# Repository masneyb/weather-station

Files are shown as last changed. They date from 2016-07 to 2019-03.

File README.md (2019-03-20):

# Solar Powered Weather Station

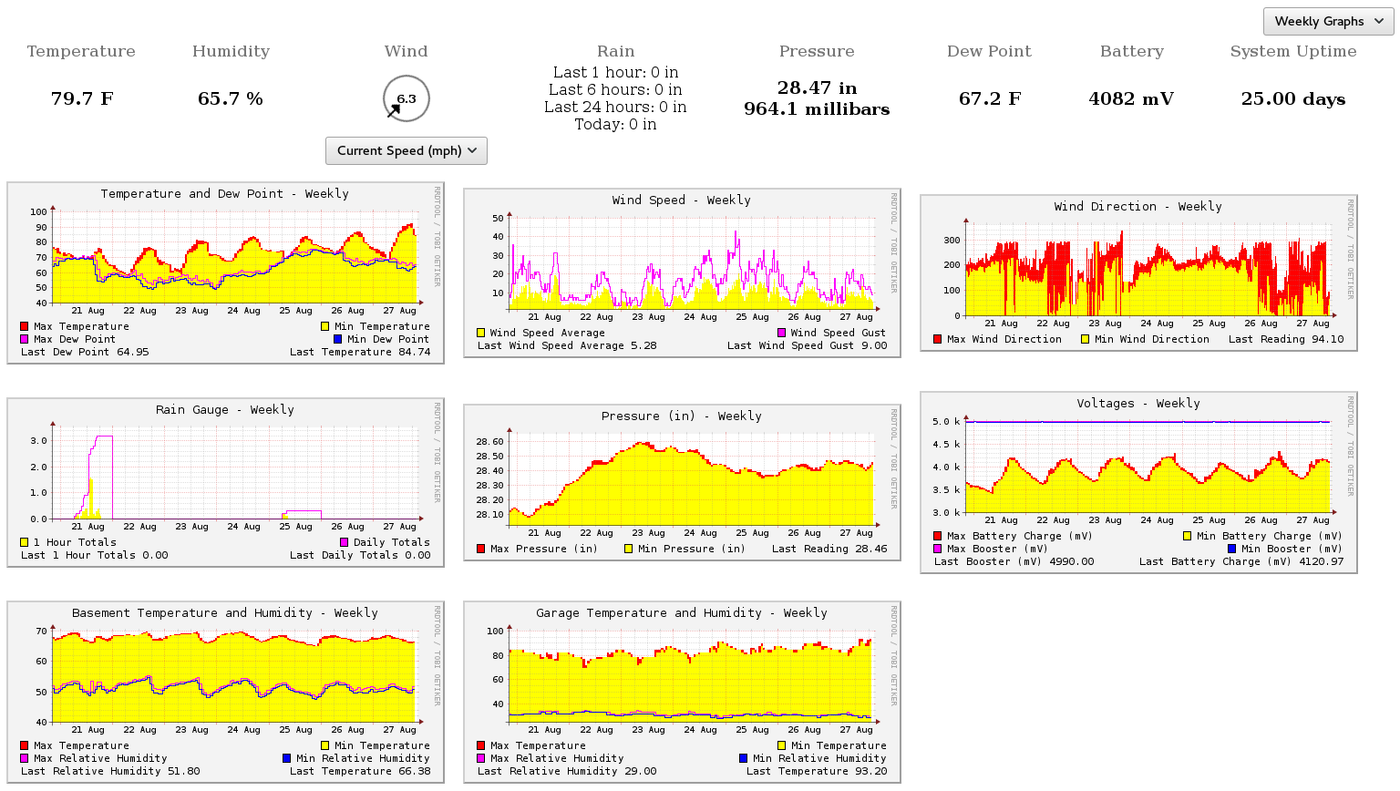
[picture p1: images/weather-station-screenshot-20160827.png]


## High level overview

- My [pi-yadl](pi-yadl) project is used to gather and graph the data from the following types
  of sensors:
  - [Argent Data Systems Weather Sensor Assembly](https://www.sparkfun.com/products/8942)
    contains a wind vane, anemometer, and rain gauge. The wind speed average and gusts
    over the last 2 minute, 10 minute and 60 minute periods are logged. The amount of
    rain over the last 1 hour, 6 hours, 24 hours, and since midnight are logged.
  - Supports various types of temperature and humidity sensors: DHT11, DHT22,
    DS18B20, TMP36 (analog).
  - Supports the BMP180 pressure, altitude and temperature sensor.
  - Battery charge level is read via an analog to digital converter (ADC).
- For the wind vane, wind speed and rain gauge, the pi-yadl program is ran
  as a daemon in the background so that it can continuously monitor the rain
  gauge and anemometer via interrupts. The values from these three sensors are
  written out to a RRD database and JSON file every 30 seconds. The wind speed
  values are updated internally every second so that it can obtain the correct
  wind gusts.
- The other sensors are polled every 5 minutes via a systemd timer and written
  to various RRD databases and JSON files.
- The RRD databases are used to show the historical readings and are
  recreated at the beginning of each hour.
- The web page uses Javascript and JQuery to download the various JSON files to
  provide a dashboard showing the current sensor readings. The web page checks
  for updated JSON files on the server every 10 seconds.
- The nginx webserver runs on the Pi and only needs to serve out static
  content. Everything runs on the Pi; no third-party services are required.
- Optional ability to publish the sensor readings to Weather Underground.
  You can
  [view my weather station on Weather Underground](https://www.wunderground.com/personal-weather-station/dashboard?ID=KWVMORGA45).

## Hardware Information

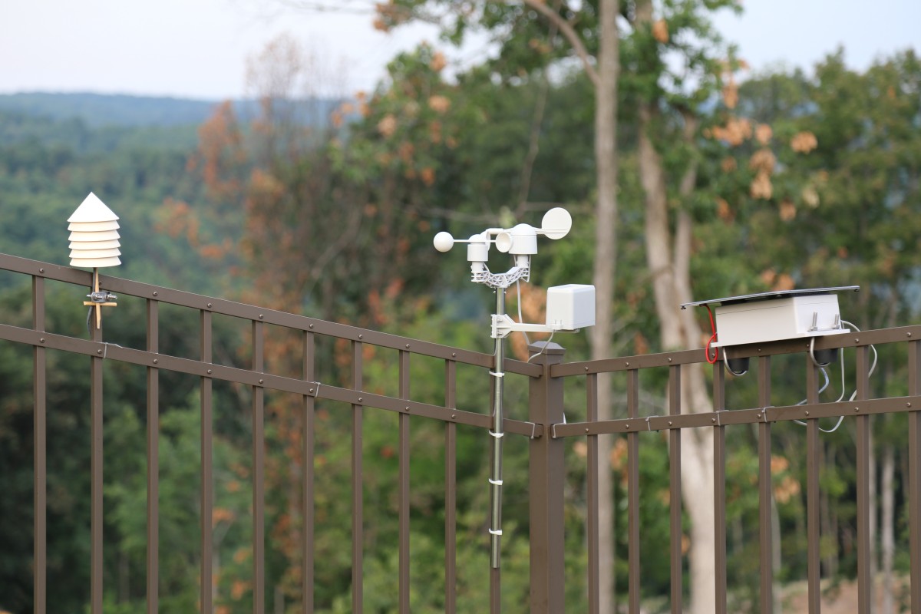
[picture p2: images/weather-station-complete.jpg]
Complete Setup


### Project Box

I used
[this project box on Amazon](https://www.amazon.com/uxcell%C2%AE-Waterproof-Connect-Junction-200x120x75mm/dp/B00O9YY1G2).
I was initially a little concerned about the quality of the seal on the box but
it has held up so after being outside continuously since June 2016.

All of the external sensors are terminated with a RJ45 connector to make it easy
to remove the project box without having to bring the entire weather station
inside. [RJ45 waterproof cable glands](https://www.adafruit.com/products/827)
are used on the project box to get the connections inside the box. The wire for
the solar panel enters the project box using a
[PG-9](https://www.adafruit.com/products/761) cable gland.

The box is mounted to the top of my fence using hose clamps with some rubber
stops that were purchased at a local hardware store.

### Solar and Power Setup

This weather station runs on a Raspberry Pi Zero running the latest Raspbian
Testing Lite. All of the hardware is powered by a
[6600mAH 3.7V lithium ion battery](https://www.adafruit.com/products/353)
that is [charged](https://www.adafruit.com/products/390) using a
[6V 9W solar panel](https://www.adafruit.com/products/2747). The 3.7V is
converted to 5V using a [PowerBoost 1000](https://www.adafruit.com/products/2465).
The solar panel is attached to the top of the project box using several large
pieces of Velcro. More information about the solar setup can be found on
[Adafruit's Website](https://learn.adafruit.com/usb-dc-and-solar-lipoly-charger/overview).
Be sure to connect the PowerBoost 1000 to the battery charge output pins; not to
the load terminal. This is because the solar panel can put out 6V however the
PowerBoost can only accept a maximum input voltage of 5.5V. See
[this post](https://forums.adafruit.com/viewtopic.php?f=19&t=59523) on the Adafruit
forums for more details. There should not be anything hooked up to the load
terminal on the charger. I fried a Pi Zero and a PowerBoost 1000 on a bright,
sunny afternoon with the PowerBoost hooked up to the load terminal.

To reduce the power usage of the Raspberry Pi, the LED and display on the Pi was
disabled. `powertop --auto-tune` was used to enable other power saving features.
See the files
[systemd/power-savings.service](systemd/power-savings.service) and
[bin/power-savings](bin/power-savings) for details. The power requirements
could be reduced even further by desoldering the various LEDs on the solar
charger and PowerBoost 1000.

I used a [USB Charger Doctor](https://www.adafruit.com/products/1852) to roughly
measure the power utilization of the entire weather station at 140 mAH with just
the wind / rain collector running in the background and 200 mAH when the main
collection processes runs every 5 minutes for just a few seconds. This is with a
USB WiFi dongle running the entire time. I would expect to get around 35 hours
of usage on a fully charged battery without any kind of backup from the solar
panel. See Power Disclaimer section below for more details.

The end of the solar panel is terminated with one of
[these waterproof cables](https://www.adafruit.com/products/744) to make it
easy to detach the solar panel from the box. This would also make it easy to
run an extension cord outside and plug the unit in to charge without removing
or disassembling the project box if there were several days in a row of very
cloudy weather.

I mounted this [waterproof on / off switch](https://www.adafruit.com/products/917)
on the project box. Two wires from the switch go to the run pins on the
PowerBoost 1000. I initially had it connected to the run pins on the Raspberry
Pi Zero but I ran into a situation where the weather station battery got very
low and I could not reset the Pi using the power button on the outside, even
after the battery was fully charged. Being able to completely power off the Pi
itself resolved that issue.

### Sensors

A [MCP3008 analog to digital converter](https://www.adafruit.com/products/856)
was soldered onto a [solderable breadboard](https://www.sparkfun.com/products/12070).
The ADC is used for the wind vane and obtaining the voltage levels from the
battery and PowerBoost 1000. This ADC communicates with the Raspberry Pi
using the SPI bus.

The wind vane supports reporting 16 different positions by using a series of
reed switches and different size resistors. The wind vane is connected to the
ADC and the voltage indicates the direction. For example, according to the 
[data sheet](http://www.sparkfun.com/datasheets/Sensors/Weather/Weather%20Sensor%20Assembly..pdf), 0 degrees (N)
is 3.84V; 45 degrees (NE) is 2.25V; and 90 degrees (E) is 0.45V. I had an issue
with getting accurate readings from the wind vane between 270 and 337.5 degrees
that was caused by having the reference ADC voltage in software set to 5V
instead of 5.1V when converting the value read from the ADC to millivolts.
Adding the argument `--adc_millivolts 5100` to the yadl binary fixed the issue.

The anemometer is hooked up to a GPIO pin on the Pi. According to the
[data sheet](http://www.sparkfun.com/datasheets/Sensors/Weather/Weather%20Sensor%20Assembly..pdf), one click
of the reed switch over a second corresponds to a wind speed of 1.492 mph
(2.4 km/h). A pull down resistor is used and the switch is debounced in
software. One complete revolution of the anemometer will cause the pin to go
high twice.

The rain gauge is very similar to the anemometer. Each click of the switch
over a second corresponds to 0.011 inches (0.2794 mm) of rain according to
the [data sheet](http://www.sparkfun.com/datasheets/Sensors/Weather/Weather%20Sensor%20Assembly..pdf).
This also uses a pull down resistor and the switch is debounced in
software.

The Stevenson screen (left side of the above picture) contains the temperature,
humidity and barometric pressure sensors. A 3D model of the screen was
downloaded from
[https://www.thingiverse.com/thing:158039](https://www.thingiverse.com/thing:158039),
3D printed using HIPS plastic and spray painted using flat white paint.

The temperature and humidity is obtained using a DHT22 sensor. The dew point is
calculated using the
[August-Roche-Magnus approximation](http://andrew.rsmas.miami.edu/bmcnoldy/Humidity.html).
The DHT sensor communicates with the Pi over one of the GPIO pins.

A BMP180 sensor is used to obtain the barometric pressure and communicates with
the Pi over the i2c bus. The BMP180 driver came from
[this project](https://github.com/lexruee/bmp180).

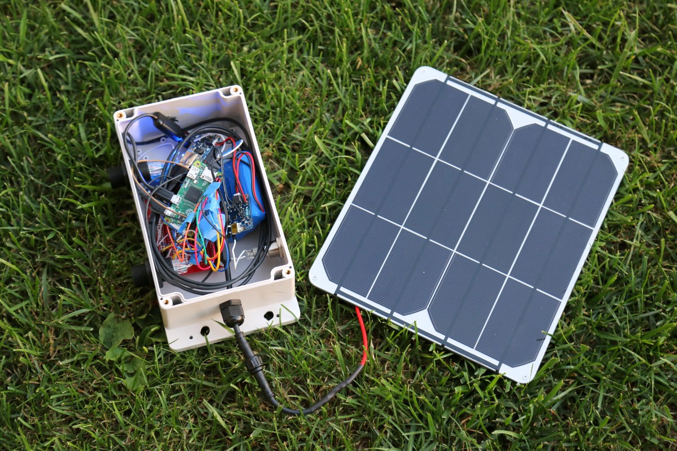
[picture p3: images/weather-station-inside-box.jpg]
Inside


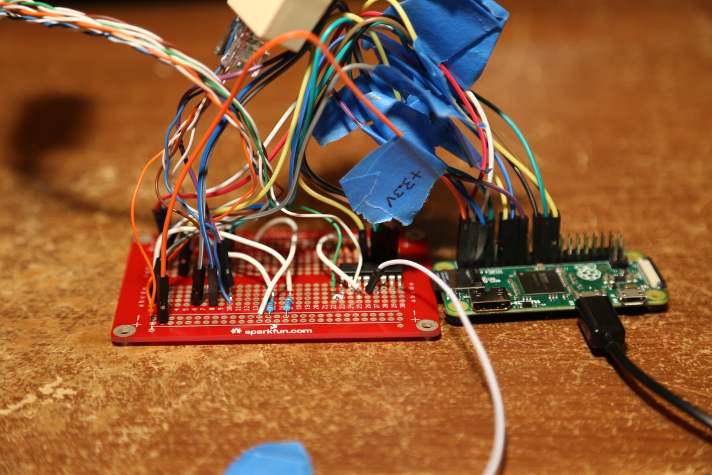
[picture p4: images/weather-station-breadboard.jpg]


The [PIN_LAYOUTS.md](PIN_LAYOUTS.md) file contains the pin layouts of the cables
that leave the box.

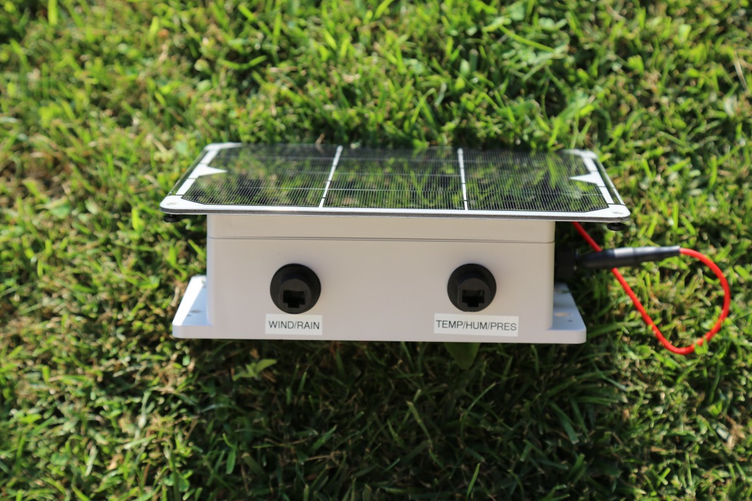
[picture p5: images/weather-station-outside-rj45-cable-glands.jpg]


Weather Underground PWS KWVMORGA45 (http://www.wunderground.com/weatherstation/WXDailyHistory.asp?ID=KWVMORGA45)

## Power Disclaimer

I have received several emails from people asking about using this setup
unattended in remote locations. The Pi Zero draws far too much power for the
size battery that I used to be used unattended in some far away location. At
the time that I wrote this (Nov 2016), Winter is approaching in the Northern
Hemisphere, and the solar panel did not completely charge the battery with the
shorter days, especially with all of the cloudy days in the area that I live.
I currently have an extension cord running from my house to the weather
station outside. At some point, I'm planning to get a large 12V battery, a
larger solar panel, associated charger, and a 12V to 5V buck buck converter
to power the weather station. The other alternative is to go with some low
powered microcontroller (such as an Arduino or one of the numerous clones),
however none of the code that I have here will run on that platform.

## Installation

- Note: This project iniitally started out using Raspian based on Debian
  Jessie, but the latest version of Raspbian Testing is required for the
  newer version of rrdtool that supports the `--left-axis-format` argument.
- Clone this repository and the [pi-yadl](https://github.com/masneyb/pi-yadl)
  repository.
- Follow the installation instructions to compile the pi-yadl project.
- Update the paths in this repository's [systemd service files](systemd/).
- Run `bin/create-rrds.sh <path to web/ directory>` to create the initial
  empty RRD databases.
- `sudo make install`
- `sudo apt-get install jq nginx`
- `sudo ln -s /path/to/web/directory /var/www/html/weather-station`

## Contact

Brian Masney <masneyb@onstation.org>

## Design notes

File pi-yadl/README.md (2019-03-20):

# pi-yadl - Yet Another Data Logger

**Note: If I was starting this weather station project over, I would use the
[Linux Industrial I/O Subsystem](https://wiki.analog.com/software/linux/docs/iio/iio)
instead of coding this. This was a good learning exercise.**

An extensible analog and digital data collector for the Raspberry Pi with the
following features:

* Supports various types of sensors and pins:
  * Supports logging raw values from digital or analog pins.
  * Supports logging the number of times that a digital pin either goes high
    or low using interrupts. Some sensors, such as rain gauges and wind
    anemometers, use a reed switch and it is up to the microcontroller to count
    the number of times that the pin changes state.
  * Supports 4 different temperature and humidity sensors: DHT11, DHT22,
    DS18B20 and TMP36 (analog). Supports multiple temperature units.
  * Supports anemometer, wind direction, and rain gauage for the
    Argent Data Systems 80422 Wind / Rain sensors. Other types of similar
    sensors should be easily supported.
  * Supports BMP180 pressure, altitude and temperature sensor. The BMP180
    driver came from [this project](https://github.com/lexruee/bmp180).
  * Supports BME280 pressure, humidity, altitude and temperature sensor. The
    BME280 driver came from
    [this project](https://github.com/andreiva/raspberry-pi-bme280).
* Supports returning the data in JSON, YAML, CSV, XML, and RRD. RRDtool can
  be used to graph the data over time. It also supports writing multiple
  files from a single sensor reading. For example, you may want to write the
  readings to a RRD database and also to a JSON file inside your web root.
* Some sensors can occasionally return erratic readings that cause large spikes
  or dips in your graphs. You can optionally set valid thresholds to ignore
  these erroneous readings.
* Supports taking multiple samples to help smooth the results. This is
  particularly useful when reading from some types of analog sensors. For
  example, you can tell the program to take 1000 samples from a sensor, discard
  the 400 samples that are the outliers and return the mean of the remaining 600
  samples.

## Usage

    usage: yadl --sensor <digital|counter|analog|dht11|dht22|ds18b20|tmp36|bmp180|bme280|argent_80422>
    	--output <json|yaml|csv|xml|rrd|single_json> [ --output <...> ]
    	[ --outfile <optional output filename. Defaults to stdout> [ --outfile <...> ] ]
    	[ --only_log_value_changes ]
    	[ --num_results <# results returned (default 1). Set to -1 to poll indefinitely.> ]
    	[ --sleep_millis_between_results <milliseconds (default 0)> ]
    	[ --num_samples_per_result <# samples (default 1). See --filter for aggregation.> ]
    	[ --sleep_millis_between_samples <milliseconds (default 0)> ]
    	[ --filter <median|mean|mode|sum|min|max|range (default median)> ]
    	[ --remove_n_samples_from_ends <# samples (default 0)> ]
    	[ --max_retries <# retries (default 20)> ]
    	[ --sleep_millis_between_retries <milliseconds (default 500)> ]
    	[ --debug ]
    	[ --logfile <path to debug logs. Uses stderr if not specified.> ]
    	[ --daemon ]
    
    Sensor Specific Options
    
    * digital - Reads from a digital pin
    	--gpio_pin <wiringPi pin #. See http://wiringpi.com/pins/>
    
    * counter - Counts the number of times the digital pin state changes.
    	--gpio_pin <wiringPi pin #. See http://wiringpi.com/pins/>
    	[ --counter_multiplier <multiplier to convert the requests per second to some other value. (default 1.0)> ]
    	[ --interrupt_edge <rising|falling|both (default rising)> ]
    
    * analog
    	--adc <see ADC options below>
    
    * dht11 / dht22 - Temperature and Humidity sensors
    	--gpio_pin <wiringPi pin #. See http://wiringpi.com/pins/>
    	--temperature_unit <celsius|fahrenheit|kelvin|rankine>
    
    * ds18b20 - Temperature sensor that uses the Dallas 1-Wire protocol.
    	--w1_slave <w1 slave device. See /sys/bus/w1/devices/28-*/w1_slave>
    	--temperature_unit <celsius|fahrenheit|kelvin|rankine>
    
    	You need to have the w1-gpio and w1-therm kernel modules loaded.
    	You'll also need to have 'dtoverlay=w1-gpio' in your /boot/config.txt
    	and reboot if it was not already present.
    
    * tmp36 - Analog temperature sensor.
    	--adc <see ADC options below>
    	--temperature_unit <celsius|fahrenheit|kelvin|rankine>
    	[ --analog_scaling_factor <value> (default 500) ]
    
    * bmp180 - Temperature, pressure and altitude sensor.
    	--i2c_address <I2C hex address. Use i2cdetect command to look up.>
    	--temperature_unit <celsius|fahrenheit|kelvin|rankine>
    
    * bme280 - Temperature, humidity, pressure and altitude sensor.
    	--i2c_address <I2C hex address. Use i2cdetect command to look up.>
    	--temperature_unit <celsius|fahrenheit|kelvin|rankine>
    
    * argent_80422 - Wind vane, anemometer, and rain gauge.
    	--wind_speed_pin <wiringPi pin #.>
    	--wind_speed_unit <mph|kmh>
    	--rain_gauage_pin <wiringPi pin #.>
    	--rain_gauage_unit <in|mm>
    	--adc <see ADC options below. This is for the wind vane.>
    
    ADC Options and Supported Types
    	[ --adc_millivolts <value (default 3300)> ]
    	[ --adc_multiplier <value (default 1.0)> ]
    
    	The --adc_multiplier can be used if have a voltage divider and
    	and want to convert the reading back to the original value.
    
    * mcp3002 / mcp3004 / mcp3008 - 10-bit ADCs with a SPI interface.
    	--spi_channel <spi channel. Either 0 or 1 for the Pi.>
    	--analog_channel <analog channel>
    
    	You need to have the proper spi_bcmXXXX kernel module loaded on the Pi.
    
    * pcf8591 - 8-bit ADC with an I2C interface.
    	--i2c_address <I2C hex address. Use i2cdetect command to look up.>
    	--analog_channel <analog channel>
    
    Examples
    
    * Poll a DHT22 temperature sensor on BCM pin 17 (wiringPi pin 0) as JSON.
      $ sudo yadl --gpio_pin 0 --sensor dht22 --temperature_unit fahrenheit --output json
      { "result": [  { "temperature": 68.18, "humidity": 55.30, "dew_point": 51.55, "temperature_unit": "F", "timestamp": 1467648942 } ] }
    
    * Show 5 averaged results from an ADC. 1000 samples are taken for each result
      shown. 200 samples from each end are removed and the mean is taken of the middle
      600 samples. This is useful for removing noise from analog sensors. Wait 2 seconds
      between each result shown.
      $ yadl --sensor analog --adc mcp3008 --spi_channel 0 --analog_channel 0 \
    	--output csv --num_results 5 --sleep_millis_between_results 2000 \
    	--num_samples_per_result 1000 --remove_n_samples_from_ends 200 --filter mean
      reading_number,timestamp,reading,millivolts
      0,1465685840,96.0,309.0
      1,1465685842,96.0,309.0
      2,1465685844,96.0,309.0
      3,1465685846,96.0,309.0
      4,1465685848,96.0,309.0
    
    * See the files in the examples/ directory for more examples.
    
    * See systemd/pi-yadl-gatherer.service for an example writing the data to
      a RRD database.

## Examples

* See my [weather station project](https://github.com/masneyb/weather-station/) for
  an example polling the different types of sensors supported by this project.
* The [examples directory](examples/) shows several more examples of how to poll
  various types of sensors.

## Graphing

See the [GRAPHING.md](GRAPHING.md) file for some tips about ways to graph the data
over time.

## Single Node Installation

* `sudo apt-get install wiringpi librrd-dev libi2c-dev`
* `make`

## Multinode Installation

See [REMOTE_POLLING.md](REMOTE_POLLING.md) for some tips on how to set it up
so that you can publish the temperature and humidity on a webserver and graph the
data on a separate computer.

## Data sheets for the supported sensors

* [MCP3002 ADC converter](http://ww1.microchip.com/downloads/en/DeviceDoc/21294C.pdf)
* [MCP3008 ADC converter](https://www.adafruit.com/datasheets/MCP3008.pdf)
* [PCF8591 ADC converter](http://www.nxp.com/documents/data_sheet/PCF8591.pdf)
* [DHT11](http://www.micropik.com/PDF/dht11.pdf)
* [DHT22](https://www.sparkfun.com/datasheets/Sensors/Temperature/DHT22.pdf)
* [DS18B20](http://cdn.sparkfun.com/datasheets/Sensors/Temp/DS18B20.pdf)
* [TMP36 analog temperature sensor](http://cdn.sparkfun.com/datasheets/Sensors/Temp/TMP35_36_37.pdf)
* [Argent Data Systems Wind / Rain Sensor Assembly](http://www.sparkfun.com/datasheets/Sensors/Weather/Weather%20Sensor%20Assembly..pdf)
* [BMP180](http://cdn.sparkfun.com/datasheets/Sensors/Pressure/BMP180.pdf)

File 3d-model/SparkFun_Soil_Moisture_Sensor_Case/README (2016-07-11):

The SparkFun Soil Moisture Sensor Case model was created by
tkramm (https://www.thingiverse.com/tkramm/about) and downloaded from
https://www.thingiverse.com/thing:1021970. It is licensed under
the Creative Commons - Attribution - Share Alike license.

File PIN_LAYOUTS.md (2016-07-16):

# RJ45 wiring pin layouts

This is mostly useful for my future reference. It contains the pin layout of
the cables that connect to the outside of the project box.

## Wind / Rain Sensors Cable

The wind / rain sensors came with two separate RJ11 terminated cables. I combined
the two cables into a single RJ45 connector to allow using the RJ45 waterproof
cable glands.

Pin | Description
----|-------------
  1 | Ground
  2 | Wind speed signal - to BCM GPIO pin #18
  3 | +5V
  4 | Wind direction - to analog channel 0 on ADC
  5 | Unused
  6 | Unused
  7 | Rain gauge signal - to BCM GPIO pin #27
  8 | +5V

## Temperature / Humidity / Barometric Pressure Cable

Pin | Description
----|-------------
  1 | DHT Temperature / Humidity Signal
  2 | Unused
  3 | DHT Temperature / Humidity +3.3V
  4 | DHT Temperature / Humidity Ground
  5 | BMP180 I2C SCL
  6 | BMP180 I2C SDA
  7 | BMP180 +3.3V
  8 | BMP180 Ground

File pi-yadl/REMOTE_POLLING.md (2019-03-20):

# Remote polling

This page describes how to make the temperature and humidity available
on a webserver as JSON. A separate node can log and graph that data.

## Installation on the temperature gathering node

Some sensors, such as the DHT11 and DHT22, require root access. This
is a restriction in wiringPi since it needs to interact with /dev/mem.
At a high level, this process sets up a webserver and uses a systemd
timer to write a JSON file every 2 minutes in the webserver document
root.

* Install dependencies: `sudo apt-get install apache2 wiringpi librrd-dev`

* Setup a systemd timer to update the JSON file every 2 minutes.

  /etc/systemd/system/yadl-json-output.service

      [Unit]
      Description=YADL
      [Service]
      User=root
      Type=simple
      ExecStart=/home/masneyb/data/weather-station/pi-yadl/bin/yadl --gpio_pin 0 --sensor dht22 --temperature_unit fahrenheit --output json --outfile /var/www/html/humiture.json

  /etc/systemd/system/yadl-json-output.timer

      [Unit]
      Description=YADL timer
      [Timer]
      OnCalendar=*:0/2
      [Install]
      WantedBy=multi-user.target

  Reload systemd and enable the services

      sudo systemctl daemon-reload
      sudo systemctl start yadl-json-output.service
      sudo systemctl start yadl-json-output.timer
      sudo systemctl enable yadl-json-output.timer

* Check that the /var/www/html/humiture.json exists and that it is being updated
  every 2 minutes. Also verify in your web browser that the URL
  http://IP_ADDRESS_TO_YOUR_PI/humiture.json returns the JSON.

## Installation on the graphing node

* Install dependencies: `sudo apt-get install librrd-dev rrdtool`

* The yadl-add-rrd-sample binary adds the temperature and humidity readings to a
  RRD database. It has the following syntax:

      usage: yadl-add-rrd-sample [ --debug ]
      		--outfile <path to RRD database>
      		--temperature <temperature>
      		--humidity <humidity>
      
      Note: A new RRD database will be created if it does not exist

* The bin/log-remote-sensor.sh shell script fetches the JSON file from
  webserver and logs it to the RRD database using the
  yadl-add-rrd-sample binary.

      usage: log-remote-sensor.sh <URL> <RRD database> <path to yadl-add-rrd-sample binary>

* Setup a systemd timer to log the remote readings to a RRD database.

  /etc/systemd/system/yadl-remote-readings.service

      [Unit]
      Description=YADL remote readings
      [Service]
      User=root
      Type=simple
      ExecStart=/home/masneyb/data/weather-station/pi-yadl/bin/log-remote-sensor.sh http://IP_ADDRESS_TO_YOUR_PI/humiture.json /home/masneyb/data/weather-station/pi-yadl/web/remote.rrd /home/masneyb/data/weather-station/pi-yadl/bin/yadl-add-rrd-sample

  /etc/systemd/system/yadl-remote-readings.timer

      [Unit]
      Description=YADL remote readings timer
      [Timer]
      OnCalendar=*:0/5
      [Install]
      WantedBy=multi-user.target

  Reload systemd and enable the services

      sudo systemctl daemon-reload
      sudo systemctl start yadl-remote-readings.service
      sudo systemctl start yadl-remote-readings.timer
      sudo systemctl enable yadl-remote-readings.timer

* Setup a systemd timer to create the graphs every hour

  /etc/systemd/system/yadl-remote-graphs.service

      [Unit]
      Description=pi-yadl remote graphs
      [Service]
      User=masneyb
      Type=simple
      ExecStart=/home/masneyb/data/weather-station/pi-yadl/bin/create-graphs.sh /home/masneyb/data/weather-station/pi-yadl/web/remote "Graph Description"

  /etc/systemd/system/yadl-remote-graphs.timer

      [Unit]
      Description=pi-yadl remote graphs timer
      [Timer]
      OnCalendar=hourly
      [Install]
      WantedBy=multi-user.target

  Reload systemd and enable the services

      sudo systemctl daemon-reload
      sudo systemctl start yadl-remote-graphs.service
      sudo systemctl start yadl-remote-graphs.timer
      sudo systemctl enable yadl-remote-graphs.timer

## Plotting multiple sensors on the same graph

Once you have multiple RRD files on a single computer, you can use RRDtool to create
a combined graph if desired. This is left as an exercise for the reader. See the
`rrdtool graph` section of bin/create-graphs.sh for a starting point. Currently, this
project creates a separate HTML page for each of the sensors.

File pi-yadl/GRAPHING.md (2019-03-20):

# How to show current and historical data on a website

If you plan to graph one or more sensors over a long period of time, then
you may want to consider using a RRD database.

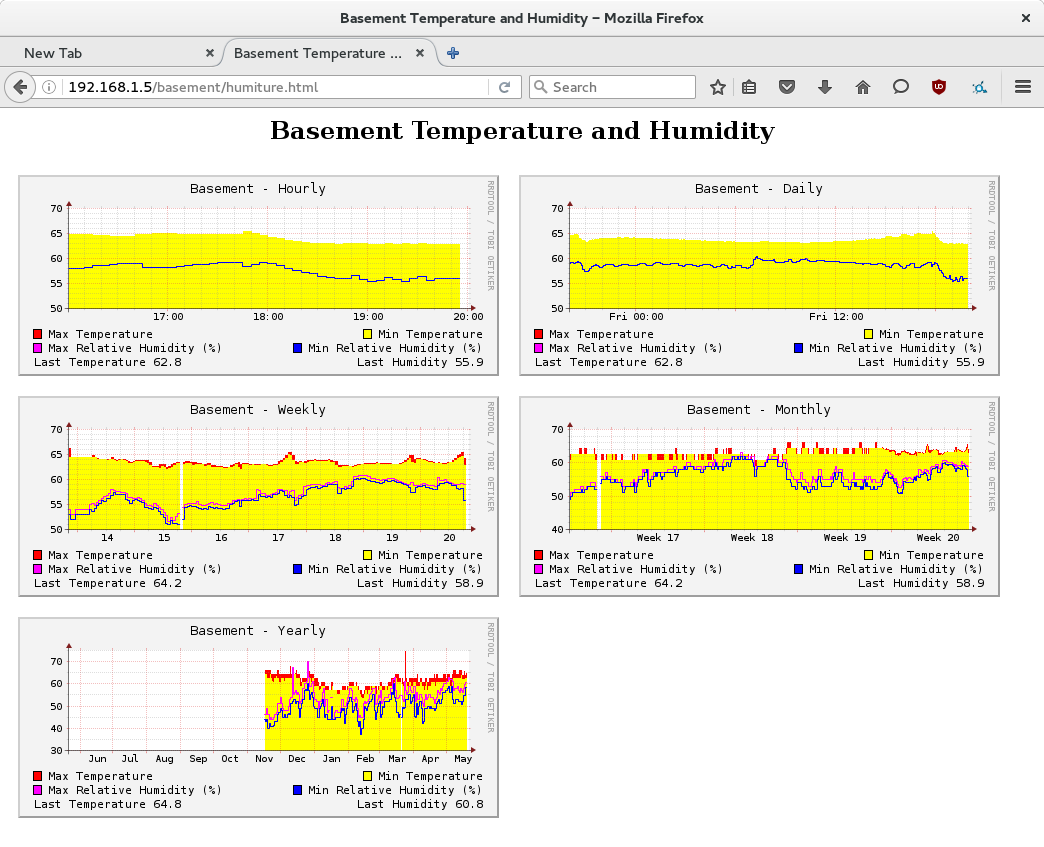
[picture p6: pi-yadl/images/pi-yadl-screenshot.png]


My [weather station](https://github.com/masneyb/weather-station) project writes the
current values to a JSON file inside the web root and to a RRD database so that the
values over time can be graphed with these arguments:

    `yadl ... --output rrd --outfile outfile.rrd --output single_json --outfile outfile.json`

# Using gnuplot to graph the data

Here is an example using the pi-yadl project to log the output from an analog
potentiometer hooked up to a 10-bit ADC.

    $ yadl --sensor analog --adc mcp3002 --spi_channel 0 --analog_channel 0 --num_results 7000 \
    				--sleep_usecs_between_results 500 --output csv --outfile data.csv

The associated [gnuplot](http://www.gnuplot.info/) script.

    set datafile separator ","
    set autoscale
    set yrange [-10:1100]
    set xtic auto
    set ytic auto
    set title "Logging an analog potentiometer using the pi-yadl project"
    set xlabel "Sample Number"
    set ylabel "ADC Reading"
    plot 'data.csv' using 1:3 with lines

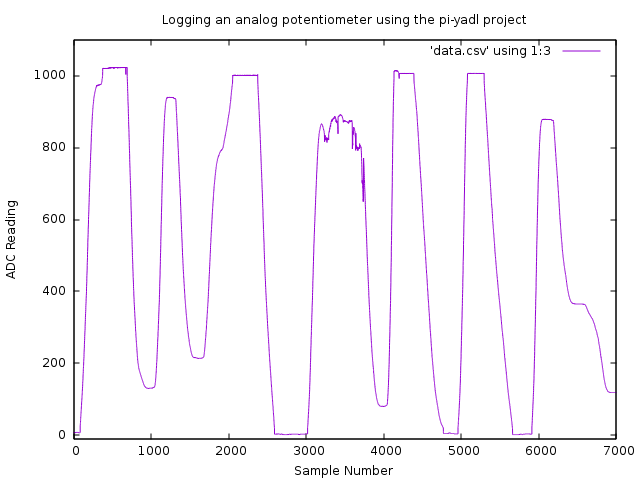
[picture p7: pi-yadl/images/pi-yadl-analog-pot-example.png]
Example using GNUplot to log the data


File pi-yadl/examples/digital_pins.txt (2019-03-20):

* Poll a single sample from BCM digital pin 17 (wiringPi pin 0) as JSON
  $ yadl --sensor digital --gpio_pin 0 --output json
  { "result": [ { "pin_state": 0.0, "timestamp": 1464465651 } ] }

* Hook a button up to a digital pin and check for bounce when the button
  is pressed. This polls the digital pin indefinitely until Crtl-C is
  pressed. Note: Newlines were added for clarity between the two button
  presses for illustration purposes.
  $ yadl --sensor digital --gpio_pin 0 --output csv --num_results -1 \
    --only_log_value_changes
  reading_number,timestamp,pin_state
  0,1464480347,0.0

  636673,1464480348,1.0
  687383,1464480348,0.0

  1678984,1464480351,1.0
  1731987,1464480351,0.0
  1731988,1464480351,1.0
  1732148,1464480351,0.0

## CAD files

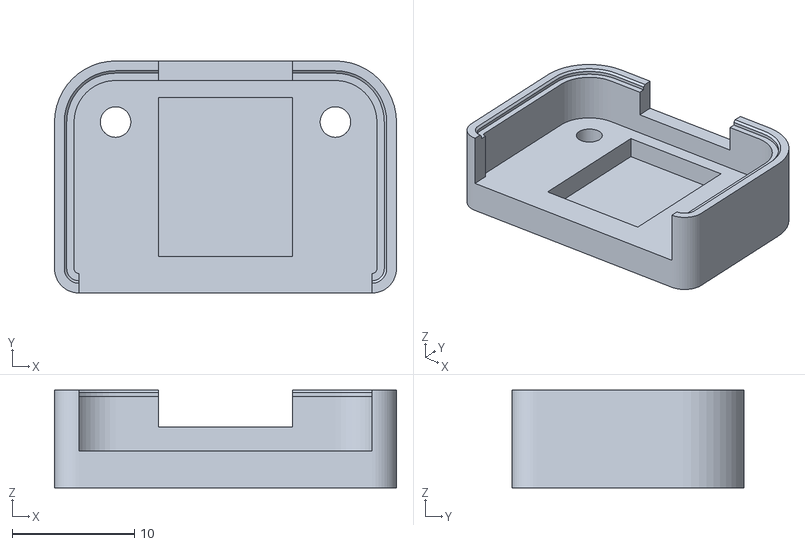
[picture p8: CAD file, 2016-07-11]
3d-model/SparkFun_Soil_Moisture_Sensor_Case/Bottom.stl
28.0 x 19.0 x 8.00

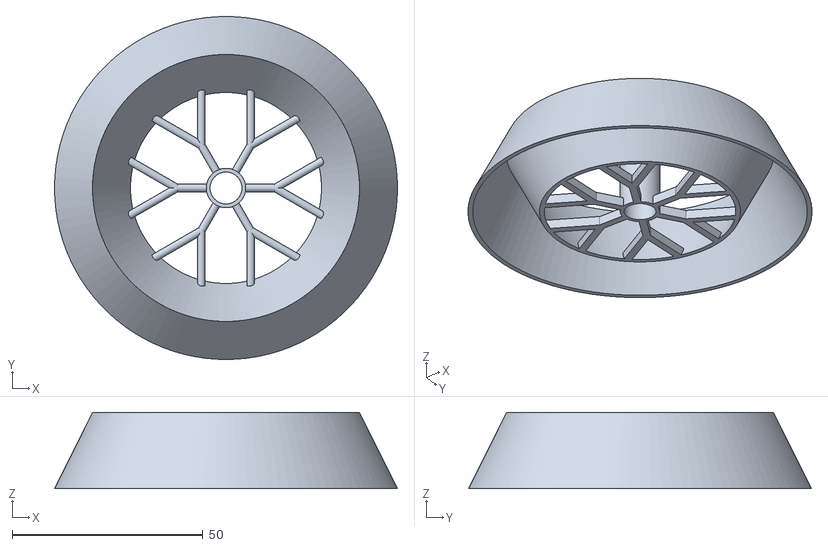
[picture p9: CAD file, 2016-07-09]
3d-model/Stevenson_Screen/Stevenson_screen_-_untere_Teile_2013-09-25.stl
89.9 x 89.9 x 20.0

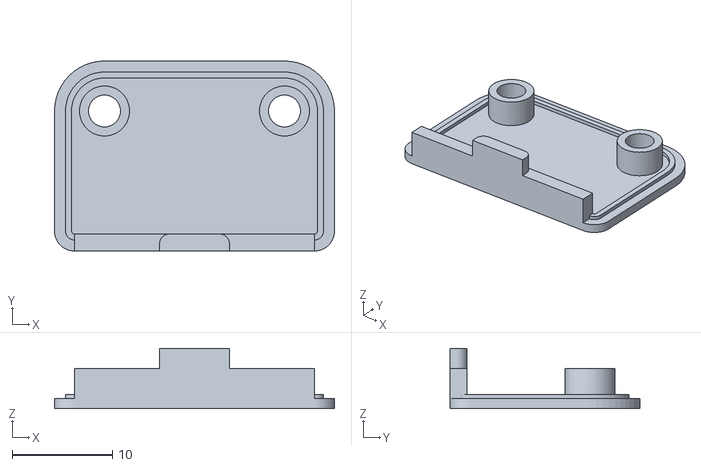
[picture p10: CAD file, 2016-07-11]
3d-model/SparkFun_Soil_Moisture_Sensor_Case/Cover.stl
28.0 x 19.0 x 6.00

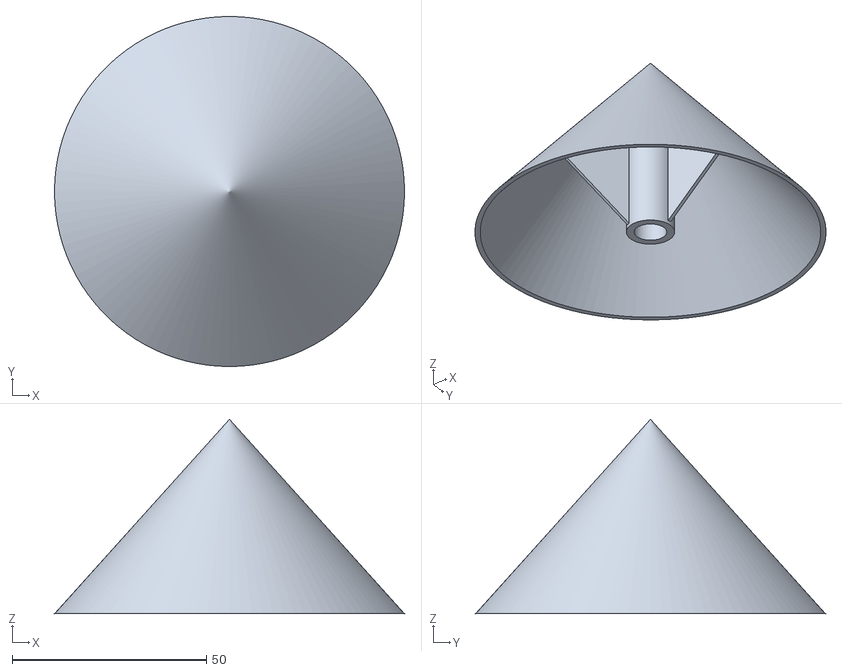
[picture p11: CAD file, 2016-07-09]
3d-model/Stevenson_Screen/Stevenson_screen_-_Kappe_2013-09-27.stl
90.0 x 90.0 x 50.0

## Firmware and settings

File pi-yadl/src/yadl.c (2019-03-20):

/*
 * yadl.c
 *
 * Copyright (C) 2016-2017 Brian Masney <masneyb@onstation.org>
 *
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
 * You should have received a copy of the GNU General Public License
 * along with this program; if not, write to the Free Software
 * Foundation, Inc., 51 Franklin Street, Fifth Floor, Boston, MA
 * 02110-1301, USA.
 */

#include <wiringPi.h>
#include <stdio.h>
#include <stdlib.h>
#include <stdint.h>
#include <string.h>
#include <errno.h>
#include <getopt.h>
#include <limits.h>
#include <unistd.h>
#include <sys/types.h>
#include "yadl.h"

#define DEFAULT_SLEEP_MILLIS_BETWEEN_RETRIES 500
#define DEFAULT_SLEEP_MILLIS_BETWEEN_SAMPLES 0
#define DEFAULT_SLEEP_MILLIS_BETWEEN_RESULTS 0
#define DEFAULT_MAX_RETRIES                 20
#define DEFAULT_NUM_SAMPLES_PER_RESULT      1
#define DEFAULT_NUM_RESULTS                 1
#define DEFAULT_REMOVE_N_SAMPLES_FROM_ENDS  0
#define DEFAULT_COUNTER_MULTIPLIER          1.0
#define DEFAULT_INTERRUPT_EDGE              "rising"
#define DEFAULT_ADC_MILLIVOLTS              3300
#define DEFAULT_ADC_MULTIPLIER              1.0
#define DEFAULT_ANALOG_SCALING_FACTOR       500

void usage(void)
{
	printf("usage: yadl --sensor <digital|counter|analog|dht11|dht22|ds18b20|tmp36|bmp180|bme280|argent_80422>\n");
	printf("\t--output <json|yaml|csv|xml|rrd|single_json> [ --output <...> ]\n");
	printf("\t[ --outfile <optional output filename. Defaults to stdout> [ --outfile <...> ] ]\n");
	printf("\t[ --only_log_value_changes ]\n");
	printf("\t[ --num_results <# results returned (default %d). Set to -1 to poll indefinitely.> ]\n", DEFAULT_NUM_RESULTS);
	printf("\t[ --sleep_millis_between_results <milliseconds (default %d)> ]\n", DEFAULT_SLEEP_MILLIS_BETWEEN_RESULTS);
	printf("\t[ --num_samples_per_result <# samples (default %d). See --filter for aggregation.> ]\n", DEFAULT_NUM_SAMPLES_PER_RESULT);
	printf("\t[ --sleep_millis_between_samples <milliseconds (default %d)> ]\n", DEFAULT_SLEEP_MILLIS_BETWEEN_SAMPLES);
	printf("\t[ --filter <median|mean|mode|sum|min|max|range (default median)> ]\n");
	printf("\t[ --remove_n_samples_from_ends <# samples (default %d)> ]\n",
	       DEFAULT_REMOVE_N_SAMPLES_FROM_ENDS);
	printf("\t[ --max_retries <# retries (default %d)> ]\n",
	       DEFAULT_MAX_RETRIES);
	printf("\t[ --sleep_millis_between_retries <milliseconds (default %d)> ]\n", DEFAULT_SLEEP_MILLIS_BETWEEN_RETRIES);
	printf("\t[ --debug ]\n");
	printf("\t[ --logfile <path to debug logs. Uses stderr if not specified.> ]\n");
	printf("\t[ --daemon ]\n");
	printf("\n");
	printf("Sensor Specific Options\n");
	printf("\n");
	printf("* digital - Reads from a digital pin\n");
	printf("\t--gpio_pin <wiringPi pin #. See http://wiringpi.com/pins/>\n");
	printf("\n");
	printf("* counter - Counts the number of times the digital pin state changes.\n");
	printf("\t--gpio_pin <wiringPi pin #. See http://wiringpi.com/pins/>\n");
	printf("\t[ --counter_multiplier <multiplier to convert the requests per second to some other value. (default %.1f)> ]\n", DEFAULT_COUNTER_MULTIPLIER);
	printf("\t[ --interrupt_edge <rising|falling|both (default %s)> ]\n",
	       DEFAULT_INTERRUPT_EDGE);
	printf("\n");
	printf("* analog\n");
	printf("\t--adc <see ADC options below>\n");
	printf("\n");
	printf("* dht11 / dht22 - Temperature and Humidity sensors\n");
	printf("\t--gpio_pin <wiringPi pin #. See http://wiringpi.com/pins/>\n");
	printf("\t--temperature_unit <celsius|fahrenheit|kelvin|rankine>\n");
	printf("\n");
	printf("* ds18b20 - Temperature sensor that uses the Dallas 1-Wire protocol.\n");
	printf("\t--w1_slave <w1 slave device. See /sys/bus/w1/devices/28-*/w1_slave>\n");
	printf("\t--temperature_unit <celsius|fahrenheit|kelvin|rankine>\n");
	printf("\n");
	printf("\tYou need to have the w1-gpio and w1-therm kernel modules loaded.\n");
	printf("\tYou'll also need to have 'dtoverlay=w1-gpio' in your /boot/config.txt\n");
	printf("\tand reboot if it was not already present.\n");
	printf("\n");
	printf("* tmp36 - Analog temperature sensor.\n");
	printf("\t--adc <see ADC options below>\n");
	printf("\t--temperature_unit <celsius|fahrenheit|kelvin|rankine>\n");
	printf("\t[ --analog_scaling_factor <value> (default %d) ]\n",
	       DEFAULT_ANALOG_SCALING_FACTOR);
	printf("\n");
	printf("* bmp180 - Temperature, pressure and altitude sensor.\n");
	printf("\t--i2c_address <I2C hex address. Use i2cdetect command to look up.>\n");
	printf("\t--temperature_unit <celsius|fahrenheit|kelvin|rankine>\n");
	printf("\n");
	printf("* bme280 - Temperature, humidity, pressure and altitude sensor.\n");
	printf("\t--i2c_address <I2C hex address. Use i2cdetect command to look up.>\n");
	printf("\t--temperature_unit <celsius|fahrenheit|kelvin|rankine>\n");
	printf("\n");
	printf("* argent_80422 - Wind vane, anemometer, and rain gauge.\n");
	printf("\t--wind_speed_pin <wiringPi pin #.>\n");
	printf("\t--wind_speed_unit <mph|kmh>\n");
	printf("\t--rain_gauage_pin <wiringPi pin #.>\n");
	printf("\t--rain_gauage_unit <in|mm>\n");
	printf("\t--adc <see ADC options below. This is for the wind vane.>\n");
	printf("\n");
	printf("ADC Options and Supported Types\n");
	printf("\t[ --adc_millivolts <value (default %d)> ]\n",
	       DEFAULT_ADC_MILLIVOLTS);
	printf("\t[ --adc_multiplier <value (default %.1f)> ]\n",
	       DEFAULT_ADC_MULTIPLIER);
	printf("\n");
	printf("\tThe --adc_multiplier can be used if have a voltage divider and\n");
	printf("\tand want to convert the reading back to the original value.\n");
	printf("\n");
	printf("* mcp3002 / mcp3004 / mcp3008 - 10-bit ADCs with a SPI interface.\n");
	printf("\t--spi_channel <spi channel. Either 0 or 1 for the Pi.>\n");
	printf("\t--analog_channel <analog channel>\n");
	printf("\n");
	printf("\tYou need to have the proper spi_bcmXXXX kernel module loaded on the Pi.\n");
	printf("\n");
	printf("* pcf8591 - 8-bit ADC with an I2C interface.\n");
	printf("\t--i2c_address <I2C hex address. Use i2cdetect command to look up.>\n");
	printf("\t--analog_channel <analog channel>\n");
	printf("\n");
	printf("Examples\n");
	printf("\n");
	printf("* Poll a DHT22 temperature sensor on BCM pin 17 (wiringPi pin 0) as JSON.\n");
	printf("  $ sudo yadl --gpio_pin 0 --sensor dht22 --temperature_unit fahrenheit --output json\n");
	printf("  { \"result\": [  { \"temperature\": 68.18, \"humidity\": 55.30, \"dew_point\": 51.55, \"temperature_unit\": \"F\", \"timestamp\": 1467648942 } ] }\n");
	printf("\n");
	printf("* Show 5 averaged results from an ADC. 1000 samples are taken for each result\n");
	printf("  shown. 200 samples from each end are removed and the mean is taken of the middle\n");
	printf("  600 samples. This is useful for removing noise from analog sensors. Wait 2 seconds\n");
	printf("  between each result shown.\n");
	printf("  $ yadl --sensor analog --adc mcp3008 --spi_channel 0 --analog_channel 0 \\\n");
	printf("	--output csv --num_results 5 --sleep_millis_between_results 2000 \\\n");
	printf("	--num_samples_per_result 1000 --remove_n_samples_from_ends 200 --filter mean\n");
	printf("  reading_number,timestamp,reading,millivolts\n");
	printf("  0,1465685840,96.0,309.0\n");
	printf("  1,1465685842,96.0,309.0\n");
	printf("  2,1465685844,96.0,309.0\n");
	printf("  3,1465685846,96.0,309.0\n");
	printf("  4,1465685848,96.0,309.0\n");
	printf("\n");
	printf("* See the files in the examples/ directory for more examples.\n");
	printf("\n");
	printf("* See systemd/pi-yadl-gatherer.service for an example writing the data to\n");
	printf("  a RRD database.\n");
	printf("\n");

	exit(1);
}

int get_num_values(yadl_config *config)
{
	char **header_names = config->sens->get_value_header_names(config);
	int i = 0;

	for (; header_names[i] != NULL; i++)
		;
	return i;
}

static void _free_result(yadl_result *result)
{
	free(result->value);
	if (result->unit != NULL)
		free(result->unit);
	free(result);
}

static yadl_result *_perform_reading(yadl_config *config)
{
	yadl_result *result;

	int success = 0;

	for (int i = 0; i < config->max_retries; i++) {
		if (i > 0 && config->sleep_millis_between_retries > 0)
			delay(config->sleep_millis_between_retries);

		result = config->sens->read(config);
		if (result == NULL) {
			/* bad reading */
			continue;
		}

		success = 1;
		break;
	}

	if (!success) {
		fprintf(stderr, "Error: Reached maximum retries.\n");
		exit(1);
	}

	return result;
}

static float_node *_add_sample_to_sorted_list(float value, float_node *list)
{
	float_node *newnode = malloc(sizeof(*newnode));

	newnode->value = value;
	newnode->next = NULL;

	if (list == NULL)
		return newnode;

	/* Add to head of list */
	if (list->value > value) {
		newnode->next = list;
		return newnode;
	}

	float_node *lastnode = list;

	/* Add to middle of list */
	for (float_node *cur = list->next; cur != NULL; cur = cur->next) {
		if (cur->value > value) {
			newnode->next = cur;
			lastnode->next = newnode;
			return list;
		}
		lastnode = cur;
	}

	/* Add to end of list */
	lastnode->next = newnode;
	return list;
}

static void _dump_list(char *description, float_node *list, yadl_config *config)
{
	config->logger("%s: Sorted values are:", description);
	for (float_node *val = list; val != NULL; val = val->next)
		config->logger(" %.2f", val->value);
	config->logger("\n");
}

static float_node *_remove_outliers(float_node *list, yadl_config *config)
{
	if (config->remove_n_samples_from_ends <= 0)
		return list;

	float_node *last_node_on_head_of_list = NULL;
	float_node *cur = list;

	for (int i = 0;
	     i < config->num_samples_per_result - config->remove_n_samples_from_ends - 1;
	     i++) {
		if (i == (config->remove_n_samples_from_ends - 1))
			last_node_on_head_of_list = cur;
		cur = cur->next;
	}

	/* Chop off the end of the list */
	free_list(cur->next);
	cur->next = NULL;

	/* Chop off the head of the list */
	float_node *new_head_of_list = last_node_on_head_of_list->next;

	last_node_on_head_of_list->next = NULL;
	free_list(list);

	return new_head_of_list;
}

static yadl_result *_perform_all_readings(yadl_config *config)
{
	float_node **value_list;

	char **header_names = config->sens->get_value_header_names(config);
	int num_values = get_num_values(config);

	value_list = calloc(num_values, sizeof(float *));

	char **unit_values = NULL;

	for (int i = 0; i < config->num_samples_per_result; i++) {
		if (i > 0 && config->sleep_millis_between_samples > 0)
			delay(config->sleep_millis_between_samples);

		yadl_result *sample = _perform_reading(config);

		/* Save the units for the returned result */
		if (i == 0 && sample->unit != NULL) {
			unit_values = sample->unit;
			sample->unit = NULL;
		}

		config->logger("Sample #%d", i);
		for (int num = 0; num < num_values; num++) {
			config->logger(", %s=%.2f", header_names[num],
				       sample->value[num]);
			value_list[num] = _add_sample_to_sorted_list(sample->value[num],
								     value_list[num]);
		}
		config->logger("\n");

		_free_result(sample);
	}

	for (int num = 0; num < num_values; num++) {
		_dump_list(header_names[num], value_list[num], config);
		value_list[num] = _remove_outliers(value_list[num], config);
		_dump_list("Values(after removing outliers)", value_list[num],
			   config);
	}

	yadl_result *result = malloc(sizeof(*result));

	result->unit = unit_values;
	result->value = malloc(sizeof(float) * num_values);
	for (int num = 0; num < num_values; num++) {
		result->value[num] = config->filter_func(value_list[num]);
		free_list(value_list[num]);
	}
	free(value_list);

	return result;
}

static void _dofork(yadl_config *config)
{
	pid_t pid;

	pid = fork();
	if (pid < 0) {
		fprintf(stderr, "Error forking: %s\n", strerror(errno));
		exit(1);
	} else if (pid > 0) {
		config->logger("Terminating parent process %d\n", pid);
		/* In parent process */
		exit(0);
	}

	/* Now running in child process */
}

static void _daemonize(yadl_config *config)
{
	config->logger("Note: Running in daemon mode\n");

	if (chdir("/") < 0) {
		fprintf(stderr, "Error changing current path to /: %s\n",
			strerror(errno));
		exit(1);
	}

	_dofork(config);
	_dofork(config);

	if (setsid() < 0) {
		fprintf(stderr, "Error calling setsid(): %s\n",
			strerror(errno));
		exit(1);
	}

	close(0);
	close(1);
	close(2);
}

int main(int argc, char **argv)
{
	static struct option long_options[] = {
		{"gpio_pin", required_argument, 0, 0 },
		{"output", required_argument, 0, 0 },
		{"sensor", required_argument, 0, 0 },
		{"debug", no_argument, 0, 0 },
		{"outfile", required_argument, 0, 0 },
		{"spi_channel", required_argument, 0, 0 },
		{"adc", required_argument, 0, 0 },
		{"max_retries", required_argument, 0, 0 },
		{"sleep_millis_between_retries", required_argument, 0, 0 },
		{"num_samples_per_result", required_argument, 0, 0 },
		{"analog_channel", required_argument, 0, 0 },
		{"sleep_millis_between_samples", required_argument, 0, 0 },
		{"filter", required_argument, 0, 0 },
		{"remove_n_samples_from_ends", required_argument, 0, 0 },
		{"num_results", required_argument, 0, 0 },
		{"sleep_millis_between_results", required_argument, 0, 0 },
		{"i2c_address", required_argument, 0, 0 },
		{"only_log_value_changes", no_argument, 0, 0 },
		{"counter_multiplier", required_argument, 0, 0 },
		{"logfile", required_argument, 0, 0 },
		{"daemon", no_argument, 0, 0 },
		{"interrupt_edge", required_argument, 0, 0 },
		{"adc_millivolts", required_argument, 0, 0 },
		{"temperature_unit", required_argument, 0, 0 },
		{"w1_slave", required_argument, 0, 0 },
		{"analog_scaling_factor", required_argument, 0, 0 },
		{"wind_speed_pin", required_argument, 0, 0 },
		{"rain_gauge_pin", required_argument, 0, 0 },
		{"wind_speed_unit", required_argument, 0, 0 },
		{"rain_gauge_unit", required_argument, 0, 0 },
		{"adc_multiplier", required_argument, 0, 0 },
		{0, 0, 0, 0 }
	};

	char *sensor_name = NULL, *adc_name = NULL;
	char *filter_name = NULL, *logfile = NULL;
	char *temperature_unit = NULL;
	yadl_config config;

	char **output_types = NULL;
	int num_output_types = 0;
	char **output_filenames = NULL;
	int num_output_filenames = 0;

	outputter **output_funcs = NULL;

	int opt = 0, long_index = 0, debug = 0, daemon = 0;

	if (argc <= 1)
		usage();

	memset(&config, 0, sizeof(config));
	config.gpio_pin = -1;
	config.spi_channel = -1;
	config.i2c_address = -1;
	config.max_retries = DEFAULT_MAX_RETRIES;
	config.sleep_millis_between_retries = DEFAULT_SLEEP_MILLIS_BETWEEN_RETRIES;
	config.sleep_millis_between_samples = DEFAULT_SLEEP_MILLIS_BETWEEN_SAMPLES;
	config.analog_channel = -1;
	config.num_results = DEFAULT_NUM_RESULTS;
	config.num_samples_per_result = DEFAULT_NUM_SAMPLES_PER_RESULT;
	config.remove_n_samples_from_ends = DEFAULT_REMOVE_N_SAMPLES_FROM_ENDS;
	config.sleep_millis_between_samples = DEFAULT_SLEEP_MILLIS_BETWEEN_SAMPLES;
	config.only_log_value_changes = 0;
	config.counter_multiplier = DEFAULT_COUNTER_MULTIPLIER;
	config.interrupt_edge = DEFAULT_INTERRUPT_EDGE;
	config.adc_millivolts = DEFAULT_ADC_MILLIVOLTS; /* Raspberry Pi GPIO pins are 3.3V */
	config.adc_multiplier = DEFAULT_ADC_MULTIPLIER;
	config.analog_scaling_factor = DEFAULT_ANALOG_SCALING_FACTOR;
	config.wind_speed_pin = -1;
	config.rain_gauge_pin = -1;

	while ((opt = getopt_long(argc, argv, "", long_options,
				  &long_index)) != -1) {
		if (opt != 0)
			usage();

		errno = 0;
		switch (long_index) {
		case 0:
			config.gpio_pin = strtol(optarg, NULL, 10);
			break;
		case 1:
			num_output_types++;
			output_types = realloc(output_types,
					       sizeof(char *) * num_output_types);
			output_types[num_output_types - 1] = optarg;
			break;
		case 2:
			sensor_name = optarg;
			break;
		case 3:
			debug = 1;
			break;
		case 4:
			num_output_filenames++;
			output_filenames = realloc(output_filenames,
						   sizeof(char *) * num_output_filenames);
			output_filenames[num_output_filenames - 1] = optarg;
			break;
		case 5:
			config.spi_channel = strtol(optarg, NULL, 10);
			break;
		case 6:
			adc_name = optarg;
			break;
		case 7:
			config.max_retries = strtol(optarg, NULL, 10);
			break;
		case 8:
			config.sleep_millis_between_retries = strtol(optarg, NULL, 10);
			break;
		case 9:
			config.num_samples_per_result = strtol(optarg, NULL, 10);
			break;
		case 10:
			config.analog_channel = strtol(optarg, NULL, 10);
			break;
		case 11:
			config.sleep_millis_between_samples = strtol(optarg, NULL, 10);
			break;
		case 12:
			filter_name = optarg;
			break;
		case 13:
			config.remove_n_samples_from_ends = strtol(optarg, NULL, 10);
			break;
		case 14:
			config.num_results = strtol(optarg, NULL, 10);
			break;
		case 15:
			config.sleep_millis_between_results = strtol(optarg, NULL, 10);
			break;
		case 16:
			config.i2c_address = strtol(optarg, NULL, 16);
			break;
		case 17:
			config.only_log_value_changes = 1;
			break;
		case 18:
			config.counter_multiplier = strtof(optarg, NULL);
			break;
		case 19:
			logfile = optarg;
			break;
		case 20:
			daemon = 1;
			break;
		case 21:
			config.interrupt_edge = optarg;
			break;
		case 22:
			config.adc_millivolts = strtol(optarg, NULL, 10);
			break;
		case 23:
			temperature_unit = optarg;
			break;
		case 24:
			config.w1_slave = optarg;
			break;
		case 25:
			config.analog_scaling_factor = strtol(optarg, NULL, 10);
			break;
		case 26:
			config.wind_speed_pin = strtol(optarg, NULL, 10);
			break;
		case 27:
			config.rain_gauge_pin = strtol(optarg, NULL, 10);
			break;
		case 28:
			config.wind_speed_unit = optarg;
			break;
		case 29:
			config.rain_gauge_unit = optarg;
			break;
		case 30:
			config.adc_multiplier = strtof(optarg, NULL);
			break;
		default:
			usage();
		}

		if (errno != 0)
			usage();
	}

	if (config.num_samples_per_result <= 0) {
		fprintf(stderr, "--num_samples_per_result must be > 0\n");
		usage();
	} else if (config.remove_n_samples_from_ends < 0) {
		fprintf(stderr, "--remove_n_samples_from_ends must be >= 0\n");
		usage();
	} else if (config.num_samples_per_result <= (config.remove_n_samples_from_ends * 2)) {
		fprintf(stderr, "--remove_n_samples_from_ends * 2 must be less than --num_samples_per_result\n");
		usage();
	} else if (daemon && debug && logfile == NULL) {
		fprintf(stderr, "You must specify the --logfile argument with --daemon\n");
		usage();
	} else if (daemon && num_output_filenames == 0) {
		fprintf(stderr, "You must specify the --outfile argument with --daemon\n");
		usage();
	}

	config.logger = get_logger(debug, logfile);

	config.sens = get_sensor(sensor_name);
	if (config.sens == NULL) {
		fprintf(stderr, "You must specify the --sensor argument\n");
		usage();
	}

	if (num_output_types == 0) {
		fprintf(stderr, "You must specify at least one --output argument\n");
		usage();
	} else if (num_output_types == 1 && num_output_filenames == 0) {
		// Send output to stdout if no filename was specified
		num_output_filenames++;
		output_filenames = realloc(output_filenames,
					   sizeof(char *) * num_output_filenames);
		output_filenames[num_output_filenames - 1] = NULL;
	} else if (num_output_types != num_output_filenames) {
		fprintf(stderr, "You must specify the same number of --output and --outfile arguments\n");
		usage();
	}

	output_funcs = malloc(sizeof(outputter *) * num_output_types);
	for (int output_idx = 0; output_idx < num_output_types; output_idx++) {
		output_funcs[output_idx] = get_outputter(output_types[output_idx]);
		if (output_funcs[output_idx] == NULL)
			usage();
	}

	config.filter_func = get_filter(filter_name);
	if (config.filter_func == NULL)
		usage();

	populate_temperature_converter(&config, temperature_unit);

	config.adc = get_adc(adc_name);

	config.logger("num_results=%d; sleep_millis_between_samples=%d; num_samples_per_result=%d; sleep_millis_between_samples=%d\n",
			config.num_results, config.sleep_millis_between_samples,
			config.num_samples_per_result,
			config.sleep_millis_between_samples);
	config.logger("max_retries=%d; sleep_millis_between_retries=%d\n",
			config.max_retries, config.sleep_millis_between_retries);

	int num_values = get_num_values(&config);

	config.last_values = malloc(sizeof(float) * num_values);

	if (wiringPiSetup() == -1)
		exit(1);

	if (daemon)
		_daemonize(&config);

	if (config.sens->init != NULL)
		config.sens->init(&config);

	output_metadata **output_metadatas = malloc(sizeof(output_metadata *) * num_output_types);

	for (int output_idx = 0; output_idx < num_output_types; output_idx++) {
		output_metadatas[output_idx] = output_funcs[output_idx]->open(&config,
									      output_filenames[output_idx]);

		if (output_funcs[output_idx]->write_header != NULL)
			output_funcs[output_idx]->write_header(output_metadatas[output_idx],
							       &config);
	}

	for (int i = 0; i < config.num_results || config.num_results < 0; i++) {
		if (i > 0 && config.sleep_millis_between_results > 0)
			delay(config.sleep_millis_between_results);

		yadl_result *result = _perform_all_readings(&config);

		for (int output_idx = 0; output_idx < num_output_types;
		     output_idx++) {
			output_funcs[output_idx]->write_result(output_metadatas[output_idx],
							       i, result,
							       &config);
		}

		_free_result(result);
	}

	for (int output_idx = 0; output_idx < num_output_types; output_idx++) {
		if (output_funcs[output_idx]->write_footer != NULL)
			output_funcs[output_idx]->write_footer(output_metadatas[output_idx]);

		if (output_funcs[output_idx]->close != NULL)
			output_funcs[output_idx]->close(output_metadatas[output_idx], &config);
	}

	close_logger(logfile);

	return 0;
}

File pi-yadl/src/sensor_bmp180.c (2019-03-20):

/*
 * The BMP180 driver code was downloaded from
 * https://github.com/lexruee/bmp180.
 *
 * The MIT License (MIT)
 *
 * Copyright (c) 2015 Alexander Rüedlinger <a.rueedlinger@gmail.com>
 * Copyright (C) 2016-2017 Brian Masney <masneyb@onstation.org>
 *
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
 * THE SOFTWARE IS PROVIDED "AS IS", WITHOUT WARRANTY OF ANY KIND, EXPRESS OR
 * IMPLIED, INCLUDING BUT NOT LIMITED TO THE WARRANTIES OF MERCHANTABILITY,
 * FITNESS FOR A PARTICULAR PURPOSE AND NONINFRINGEMENT. IN NO EVENT SHALL THE
 * AUTHORS OR COPYRIGHT HOLDERS BE LIABLE FOR ANY CLAIM, DAMAGES OR OTHER
 * LIABILITY, WHETHER IN AN ACTION OF CONTRACT, TORT OR OTHERWISE, ARISING FROM,
 * OUT OF OR IN CONNECTION WITH THE SOFTWARE OR THE USE OR OTHER DEALINGS IN THE
 * SOFTWARE.
 */

#include <wiringPiI2C.h>
#include <stdint.h>
#include <string.h>
#include <stdbool.h>
#include <stdlib.h>
#include <fcntl.h>
#include <unistd.h>
#include <errno.h>
#include <stdio.h>
#include <time.h>
#include <math.h>
#include <unistd.h>
#include <errno.h>
#include <limits.h>
#include <float.h>
#include "yadl.h"

// pressure oversampling modes
#define BMP180_PRESSURE_OSS_ULTRA_LOW_POWER 0 // ultra low power
#define BMP180_PRESSURE_OSS_STANDARD 1 // standard
#define BMP180_PRESSURE_OSS_HIGH_RESOLUTION 2 // high resolution
#define BMP180_PRESSURE_OSS_ULTRA_HIGH_RESOLUTION 3 // ultra high resoultion

// Registers
#define BMP180_REGISTER_AC1_H 0xAA
#define BMP180_REGISTER_AC2_H 0xAC
#define BMP180_REGISTER_AC3_H 0xAE
#define BMP180_REGISTER_AC4_H 0xB0
#define BMP180_REGISTER_AC5_H 0xB2
#define BMP180_REGISTER_AC6_H 0xB4
#define BMP180_REGISTER_B1_H 0xB6
#define BMP180_REGISTER_B2_H 0xB8
#define BMP180_REGISTER_MB_H 0xBA
#define BMP180_REGISTER_MC_H 0xBC
#define BMP180_REGISTER_MD_H 0xBE
#define BMP180_REGISTER_TEMPERATURE 0xF6
#define BMP180_REGISTER_PRESSURE 0xF6

#define BMP180_CTRL 0xF4

#define BMP180_TEMPERATURE_READ_CMD 0x2E
#define BMP180_TEMPERATURE_READ_WAIT_US 5000

// Pressure oversampling modes
#define BMP180_PRESSURE_OSS_ULTRA_LOW_POWER 0
#define BMP180_PRESSURE_OSS_STANDARD 1
#define BMP180_PRESSURE_OSS_HIGH_RESOLUTION 2
#define BMP180_PRESSURE_OSS_ULTRA_HIGH_RESOLUTION 3

// Pressure read commands
#define BMP180_PRESSURE_OSS_ULTRA_LOW_POWER_CMD 0x34
#define BMP180_PRESSURE_OSS_STANDARD_CMD 0x74
#define BMP180_PRESSURE_OSS_HIGH_RESOLUTION_CMD 0xB4
#define BMP180_PRESSURE_OSS_ULTRA_HIGH_RESOLUTION_CMD 0xF4

// Waiting times in us for reading pressure values
#define BMP180_PRESSURE_OSS_ULTRA_LOW_POWER_WAIT_US 5000
#define BMP180_PRESSURE_OSS_STANDARD_WAIT_US 8000
#define BMP180_PRESSURE_OSS_HIGH_RESOLUTION_WAIT_US 14000
#define BMP180_PRESSURE_OSS_ULTRA_HIGH_RESOLUTION_WAIT_US 26000

#define BMP180_AVG_PRESSURE_AT_SEA_LEVEL_IN_HPA 1013.25

// Basic structure for the bmp180 sensor
typedef struct {
	int fd;

	/* BMP180 oversampling mode */
	int oss;

	/* Eprom values */
	int32_t ac1;
	int32_t ac2;
	int32_t ac3;
	int32_t ac4;
	int32_t ac5;
	int32_t ac6;
	int32_t b1;
	int32_t b2;
	int32_t mb;
	int32_t mc;
	int32_t md;
} bmp180_t;

// Lookup table for BMP180 register addresses
static int32_t bmp180_register_table[11][2] = {
		{BMP180_REGISTER_AC1_H, 1},
		{BMP180_REGISTER_AC2_H, 1},
		{BMP180_REGISTER_AC3_H, 1},
		{BMP180_REGISTER_AC4_H, 0},
		{BMP180_REGISTER_AC5_H, 0},
		{BMP180_REGISTER_AC6_H, 0},
		{BMP180_REGISTER_B1_H, 1},
		{BMP180_REGISTER_B2_H, 1},
		{BMP180_REGISTER_MB_H, 1},
		{BMP180_REGISTER_MC_H, 1},
		{BMP180_REGISTER_MD_H, 1}
};


// Reads the eprom of this BMP180 sensor.
static void bmp180_read_eprom(bmp180_t *bmp)
{
	int32_t *bmp180_register_addr[11] = {
		&bmp->ac1, &bmp->ac2, &bmp->ac3, &bmp->ac4, &bmp->ac5,
		&bmp->ac6, &bmp->b1, &bmp->b2, &bmp->mb, &bmp->mc, &bmp->md
	};

	for (int i = 0; i < 11; i++) {
		uint8_t reg = (uint8_t) bmp180_register_table[i][0];
		uint8_t sign = (uint8_t) bmp180_register_table[i][1];

		int32_t data = wiringPiI2CReadReg16(bmp->fd, reg) & 0xFFFF;
		*(bmp180_register_addr[i]) = ((data << 8) & 0xFF00) +
			(data >> 8);
		if (sign && (*(bmp180_register_addr[i]) > 32767))
			*(bmp180_register_addr[i]) -= 65536;
	}
}

// Returns the raw measured temperature value of this BMP180 sensor.
static int32_t bmp180_read_raw_temperature(bmp180_t *bmp)
{
	wiringPiI2CWriteReg8(bmp->fd, BMP180_CTRL, BMP180_TEMPERATURE_READ_CMD);

	usleep(BMP180_TEMPERATURE_READ_WAIT_US);

	int32_t data = wiringPiI2CReadReg16(bmp->fd,
					    BMP180_REGISTER_TEMPERATURE) & 0xFFFF;

	data = ((data << 8) & 0xFF00) + (data >> 8);
	return data;
}


// Returns the raw measured pressure value of this BMP180 sensor.
static int32_t bmp180_read_raw_pressure(bmp180_t *bmp)
{
	uint16_t wait;
	uint8_t cmd;

	switch (bmp->oss) {
	case BMP180_PRESSURE_OSS_STANDARD:
		wait = BMP180_PRESSURE_OSS_STANDARD_WAIT_US;
		cmd = BMP180_PRESSURE_OSS_STANDARD_CMD;
		break;
	case BMP180_PRESSURE_OSS_HIGH_RESOLUTION:
		wait = BMP180_PRESSURE_OSS_HIGH_RESOLUTION_WAIT_US;
		cmd = BMP180_PRESSURE_OSS_HIGH_RESOLUTION_CMD;
		break;
	case BMP180_PRESSURE_OSS_ULTRA_HIGH_RESOLUTION:
		wait = BMP180_PRESSURE_OSS_ULTRA_HIGH_RESOLUTION_WAIT_US;
		cmd = BMP180_PRESSURE_OSS_ULTRA_HIGH_RESOLUTION_CMD;
		break;
	case BMP180_PRESSURE_OSS_ULTRA_LOW_POWER:
	default:
		wait = BMP180_PRESSURE_OSS_ULTRA_LOW_POWER_WAIT_US;
		cmd = BMP180_PRESSURE_OSS_ULTRA_LOW_POWER_CMD;
		break;
	}

	wiringPiI2CWriteReg8(bmp->fd, BMP180_CTRL, cmd);

	usleep(wait);

	int32_t msb = wiringPiI2CReadReg8(bmp->fd,
					  BMP180_REGISTER_PRESSURE) & 0xFF;
	int32_t lsb = wiringPiI2CReadReg8(bmp->fd,
					  BMP180_REGISTER_PRESSURE+1) & 0xFF;
	int32_t xlsb = wiringPiI2CReadReg8(bmp->fd,
					   BMP180_REGISTER_PRESSURE+2) & 0xFF;

	return ((msb << 16) + (lsb << 8) + xlsb) >> (8 - bmp->oss);
}

// Returns the measured temperature in celsius.
static float bmp180_temperature(bmp180_t *bmp)
{
	long UT = bmp180_read_raw_temperature(bmp);
	long X1 = ((UT - bmp->ac6) * bmp->ac5) >> 15;
	long X2 = (bmp->mc << 11) / (X1 + bmp->md);
	long B5 = X1 + X2;

	return ((B5 + 8) >> 4) / 10.0;
}


// Returns the measured pressure in pascal.
static long bmp180_pressure(bmp180_t *bmp)
{
	long UT = bmp180_read_raw_temperature(bmp);
	long UP = bmp180_read_raw_pressure(bmp);

	long X1 = ((UT - bmp->ac6) * bmp->ac5) >> 15;
	long X2 = (bmp->mc << 11) / (X1 + bmp->md);

	long B5 = X1 + X2;

	long B6 = B5 - 4000;

	X1 = (bmp->b2 * (B6 * B6) >> 12) >> 11;
	X2 = (bmp->ac2 * B6) >> 11;
	long X3 = X1 + X2;

	long B3 = ((((bmp->ac1 * 4) + X3) << bmp->oss) + 2) / 4;

	X1 = (bmp->ac3 * B6) >> 13;
	X2 = (bmp->b1 * ((B6 * B6) >> 12)) >> 16;
	X3 = ((X1 + X2) + 2) >> 2;

	unsigned long B4 = bmp->ac4 * (unsigned long)(X3 + 32768) >> 15;
	unsigned long B7 = ((unsigned long) UP - B3) * (50000 >> bmp->oss);

	long p;

	if (B7 < 0x80000000)
		p = (B7 * 2) / B4;
	else
		p = (B7 / B4) * 2;

	X1 = (p >> 8) * (p >> 8);
	X1 = (X1 * 3038) >> 16;
	X2 = (-7357 * p) >> 16;
	return p + ((X1 + X2 + 3791) >> 4);
}
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

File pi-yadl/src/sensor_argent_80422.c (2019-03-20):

/*
 * sensor_argent_80422.c - Supports the wind direction, wind speed,
 *                         and rain gauge.
 *
 * Copyright (C) 2016-2017 Brian Masney <masneyb@onstation.org>
 *
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
 * You should have received a copy of the GNU General Public License
 * along with this program; if not, write to the Free Software
 * Foundation, Inc., 51 Franklin Street, Fifth Floor, Boston, MA
 * 02110-1301, USA.
 */

#include <wiringPi.h>
#include <errno.h>
#include <stdio.h>
#include <stdlib.h>
#include <string.h>
#include <limits.h>
#include <pthread.h>
#include <unistd.h>
#include <time.h>
#include <sys/time.h>
#include "yadl.h"

static volatile unsigned int _wind_last_millis;
static volatile int _wind_current_counter;
static int _wind_last_counter;

static volatile unsigned int _rain_last_millis;
static volatile int _rain_current_counter;
static int _rain_last_counter;

static struct timeval _last_time;

static void _wind_speed_handler(void)
{
	unsigned int cur_millis = millis();

	if (cur_millis - _wind_last_millis > 10) {
		_wind_current_counter++;
		_wind_last_millis = cur_millis;
	}
}

static void _rain_gauge_handler(void)
{
	unsigned int cur_millis = millis();

	if (cur_millis - _rain_last_millis > 10) {
		_rain_current_counter++;
		_rain_last_millis = cur_millis;
	}
}

static int _get_num_seen(int start_counter, int stop_counter)
{
	/* Check to see if the number wrapped */
	if (stop_counter < start_counter)
		return (INT_MAX - start_counter) + stop_counter;
	return stop_counter - start_counter;
}

static void _check_wind_direction(int read_millivolts, int compare_millivolts,
				float reading, float *direction, int *distance)
{
	int this_distance = abs(read_millivolts - compare_millivolts);

	if (*direction < 0 || this_distance < *distance) {
		*direction = reading;
		*distance = this_distance;
	}
}

/* These values came from the data sheet for the Sparkfun Weather
 * Station
 * https://www.sparkfun.com/products/8942
 * http://www.sparkfun.com/datasheets/Sensors/Weather/Weather%20Sensor%20Assembly..pdf
 */
static float _get_wind_direction(yadl_config *config)
{
	float direction = -1.0;
	int distance = 0;

	int reading = config->adc->adc_read(config);
	int millivolts = (float) reading *
		((float) config->adc_millivolts /
		 (float) config->adc->adc_resolution);

	/* Find the closest reading to the values listed in the datasheet */
	_check_wind_direction(millivolts, 3840, 0.0, &direction, &distance);
	_check_wind_direction(millivolts, 1980, 22.5, &direction, &distance);
	_check_wind_direction(millivolts, 2250, 45.0, &direction, &distance);
	_check_wind_direction(millivolts, 410, 67.5, &direction, &distance);
	_check_wind_direction(millivolts, 450, 90.0, &direction, &distance);
	_check_wind_direction(millivolts, 320, 112.5, &direction, &distance);
	_check_wind_direction(millivolts, 900, 135.0, &direction, &distance);
	_check_wind_direction(millivolts, 620, 157.5, &direction, &distance);
	_check_wind_direction(millivolts, 1400, 180.0, &direction, &distance);
	_check_wind_direction(millivolts, 1190, 202.5, &direction, &distance);
	_check_wind_direction(millivolts, 3080, 225.0, &direction, &distance);
	_check_wind_direction(millivolts, 2930, 247.5, &direction, &distance);
	_check_wind_direction(millivolts, 4620, 270.0, &direction, &distance);
	_check_wind_direction(millivolts, 4040, 292.5, &direction, &distance);
	_check_wind_direction(millivolts, 4780, 315.0, &direction, &distance);
	_check_wind_direction(millivolts, 3430, 337.5, &direction, &distance);

	config->logger("Wind direction: reading=%d, %d mV, direction=%.1f degrees\n",
		       reading, millivolts, direction);

	return direction;
}
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

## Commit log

2016-05-28 initial commit of the yadl project. Basically this is currently a stripped down version of my yatl project.
2016-06-05 make sure the --gpio_pin argument was specified. Ensure that the pin is initialized correctly.
    [sensor_digital.c]
2016-06-05 added support for digital counting, which will count the number of times that the pin state goes from high to low. This is useful for logging the output from some types of sensors, such as anemometer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
2016-06-05 changed the delay unit from usecs to milliseconds
2016-06-06 added support for specifying the interrupt edge via the command line
2016-06-06 fixed multiplier for wind speed example
    [yadl.c]
2016-06-07 added support for showing the analog reading in the converted millivolts
2016-06-08 added support for having the sensors return multiple values
2016-06-08 removed duplicate call to wiringPiSetup()
2016-06-08 merged in temperature sensors from yatl project so that there is one unified project
2016-06-27 added support for polling the Argent Systems 80422 wind / rain sensors
2016-06-27 daemonize before the sensors are initialized
2016-06-27 rain gauge needs to sum the overall number of times that the pin state changes; not average it over the period
2016-06-28 added support for a sum filter
2016-06-29 argent 80422 - keep track of the last 30m, 6h and 24h rainfall totals
2016-06-30 added index.html for all of the sensors
2016-06-30 added pin layout of the wiring harness to the sensors
2016-07-04 added support for calculating the dew point for the DHT 11/22 sensors
2016-07-04 The rain gauge switch appears to be bouncing at times. Add a minimum valid time between state changes.
2016-07-04 trimmed the number of log statements in the ADC code to make the debugging output smaller
2016-07-04 shortened the column names for rrdtool
    [sensor_argent_80422.c]
2016-07-04 swapped gust direction and speeds to match the headers
    [sensor_argent_80422.c]
2016-07-08 added check for the temperature converter flag
2016-07-09 added support for the BMP180 temperature, pressure and altitude sensor
2016-07-09 added separate script to create the temperature and humidity graphs
2016-07-09 added more sensors to the weather station
2016-07-09 added 3D model for the Stevenson Screen that I printed
    [Stevenson_screen_-_Kappe_2013-09-27.stl, Stevenson_screen_-_untere_Teile_2013-09-25.stl]
2016-07-11 added sparkfun soil moisture sensor case
    [Bottom.stl, Cover.stl, Stevenson_screen_-_Kappe_2013-09-27.stl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]
2016-07-11 added script for reducing the power usage on the raspberry pi zero
2016-07-12 updated adc millivolts for my battery / solar powered setup
2016-07-12 updated to latest pin layout
2016-07-12 added more pin layout information
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2016-07-14 updated temperature sensor from a DHT11 to a DHT22
2016-07-16 powertop needs a tty to run unattended on startup
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2016-07-16 updated picture of weather station with the cables now cleaned up
2016-07-16 removed power consumption since this is wrong. It was mVH not mAH!
2016-07-16 put wind speed average and gusts on the same graph; battery and booster are also on the same graph
2016-07-17 added note about how to hook up the powerboost
2016-07-17 use the unit field in the JSON output for the temperature, dew point, and rain gauge
2016-07-17 don't exit in main program if the temperature converter is not set. Only exit if it is not present in the sensors that needed it
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2016-07-22 moved supported sensors under high level summary; added link to my weather station on weather underground
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2016-07-26 added more power savings by disabling unneeded services
2016-07-27 made wind direction graph always show 0-360; pressure graph now shows a smaller area
2016-07-28 cleaned up usage some more to make it easier to see what arguments are supported and required for the various types of sensors.
2016-07-29 don't send readings to weather underground that are not current. Only publish what is currently available.
2016-07-29 remove the JSON file if the readings are not current. Show dashes in the web interface for readings that are not current.
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2016-07-30 This is a patch that I submitted to the upstream bmp180 project.
    The call to i2c_smbus_write_byte_data() can fail and the return value
    was not being checked. This can cause incorrect values to be returned
    by the driver. With this change, when calling bmp180_temperature(),
    bmp180_pressure() and bmp180_altitude(), the return value will either
    be LONG_MIN or -FLT_MAX, depending on the return data type if the
    operation failed. The caller can call bmp180_get_last_errno() to get
    the errno of the failed operation.
    I am encountering this situation with my BMP180 sensor. It is
    currently outdoors and I believe that moisture may be causing an
    issue with the sensor. `i2cdetect 1` does not show the sens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
    [sensor_bmp180.c]
2016-07-31 removed note about the high winds. This was caused by improper voltages going to the Pi
2016-08-01 s/apache/nginx/ since nginx has lower power consumption according to powertop for a mostly idle webserver
2016-08-01 added power savings tips and clarified installation instructions
2016-08-03 added bigger battery; on/off switch; changed end of the solar panel
2016-08-11 added --left-axis-format argument to rrdgraph for the barometric pressure so that the decimal places are shown.
2016-08-11 increased the precision for logging the barometric pressure
2016-08-12 show two decimal places on the Y axis of the RRD graphs
2016-09-04 added support for the BME280 sensor. Driver came from https://github.com/andreiva/raspberry-pi-bme280.
2016-09-04 moved initialization into other function so that multiple results can be sampled. avoided use a calloc()/free() for samples
    [sensor_bme280.c]
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2016-09-05 removed some functions that I didn't need; made the code a little more streamlined
    [sensor_bmp180.c]
2016-09-05 the wiringPi i2c read/write functions don't appear to return an error code
    [sensor_bmp180.c]
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2016-11-30 Added power disclaimer about running this unattended in some far, remote location. Hook the outside power button up to the PowerBoost 1000, not the Pi Zero. Updated note about the seal on the project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
2017-05-07 take additional samples for bmp180 to reduce noise
2017-06-21 mitigate against bad readings from the pressure sensor by taking 7 samples, drop the 4 outliers, take the mean of the middle 3 samples, and waiting 1 second between each reading.
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2017-11-25 swap battery and booster colors on graph
2018-03-07 add support for the --adc_multiplier argument. This is useful for when a voltage divider is present and the reading needs to be converted back to the original sample.

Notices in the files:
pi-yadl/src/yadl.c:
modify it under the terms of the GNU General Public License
